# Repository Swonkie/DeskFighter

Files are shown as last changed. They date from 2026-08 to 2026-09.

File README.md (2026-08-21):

# DeskFighter

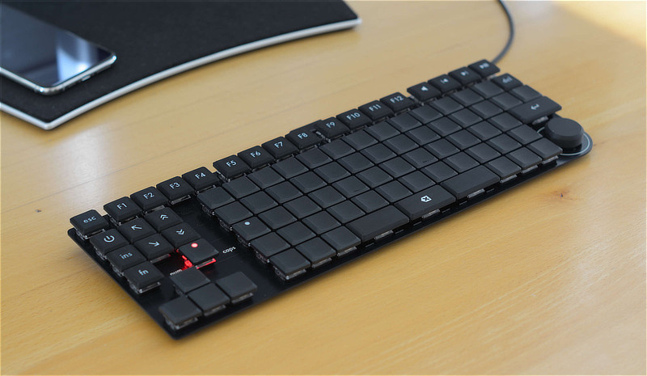
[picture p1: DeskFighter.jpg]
keyboard


These are the files used to design and build the DeskFighter keyboard.

There is an article which describes the process:

https://haldimann.app/DeskFighter/

## Organization

### 3D Printed Parts

Files in step and 3mf format to 3D print keycaps and other small parts required for the keyboard build.

### FreeCAD

FreeCAD files used to export the 3D printed parts above. If you want to make modifications, this is the most convenient option.

https://www.freecad.org/

### Keycaps Labels

Affinity and svg files used to design the labels. These were imported into FreeCAD.

### Matrix Layout

Spreadsheet used to plan the keyboard matrix layout.

### PCB

KiCad project files used to design the printed circuit board (PCB). The actual manufacturing files (gerber and drill files) are not included, but can be exported from KiCad. Those are then sent to a PCB manufacturer which will make the board.

Also includes the MacroPad files — a test project to figure out some things with a small PCB before ordering the large DeskFighter PCB.

https://www.kicad.org/

## Additional parts required

The mentioned shops are just suggestions. All parts are available in other shops too.

| Shop | Item | Quantity |
| --- | --- | ---: |
| [Keebart](https://www.keebart.com/) | Switches (Kailh Choc V2 with 2 pins) | 100 |
| | THT keycaps blank | 60 |
| | THT keycaps with dot | 2 |
| | THT keycaps with tactile marker | 2 |
| [Max Gaming](https://www.maxgaming.com/shop) | Durock V3 plate-mounted stabilizer set | 1 |
| [DigiKey](https://www.digikey.com/) | [Various electronics components](https://www.digikey.com/en/mylists/list/9PG9QW3RYC) | – |
| [CNC Kitchen](https://cnckitchen.store/) | M2 heat-set inserts | 20 |
| | Installation tip set (optional) | 1 |
| [AliExpress](https://www.aliexpress.com/) | M2 × 5 mm screws, black, Torx | 10 |
| | Rubber feet, 8 mm × 3 mm, self-adhesive | 20 |

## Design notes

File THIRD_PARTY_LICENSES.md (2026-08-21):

Some files in this repository are licensed differently than the repository itself:

## SW_Kailh_Choc_V2.step

3D model by GitHub user koktoh licensed under CC BY-NC-SA 4.0

https://github.com/koktoh/keyswitch_model/blob/master/choc/v2/step/red.step

https://creativecommons.org/licenses/by-nc-sa/4.0/

### Changes made

- removed third pin, which is not present in newer version of the switch

## Stabilizer_2.00u.step

3D model by GitHub user koktoh licensed under CC BY-NC-SA 4.0

https://github.com/koktoh/keyswitch_model/blob/master/stabilizer/plate_mount/step/stabilizer_2u.step

https://creativecommons.org/licenses/by-nc-sa/4.0/

## RING23-920205-TH.step

3D model by manufacturer (Same Sky)

https://www.sameskydevices.com/product/resource/digikey3dmodel/ring23-920205-th

https://www.sameskydevices.com/cad-model-terms

## GSB1C41110SSHR.step

3D model by manufacturer (Amphenol ICC)

Provided by DigiKey with download agreement on same page:

https://www.digikey.com/en/models/21623839

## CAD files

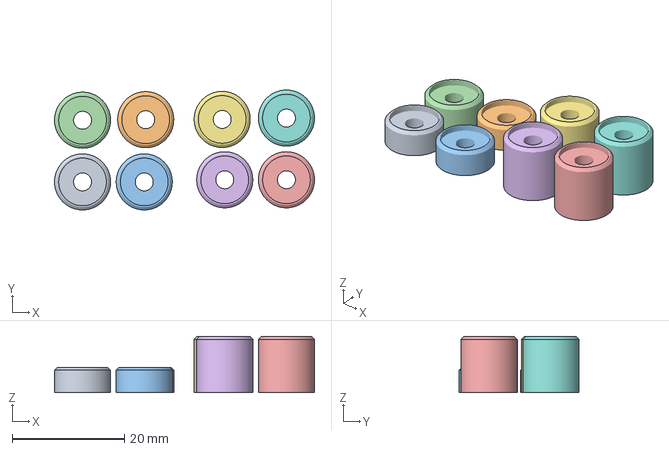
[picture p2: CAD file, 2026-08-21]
3D Printed Parts/Feet.3mf
46.3 x 21.4 x 10.0 mm
Foot Front.step x 4
Standoff x 4

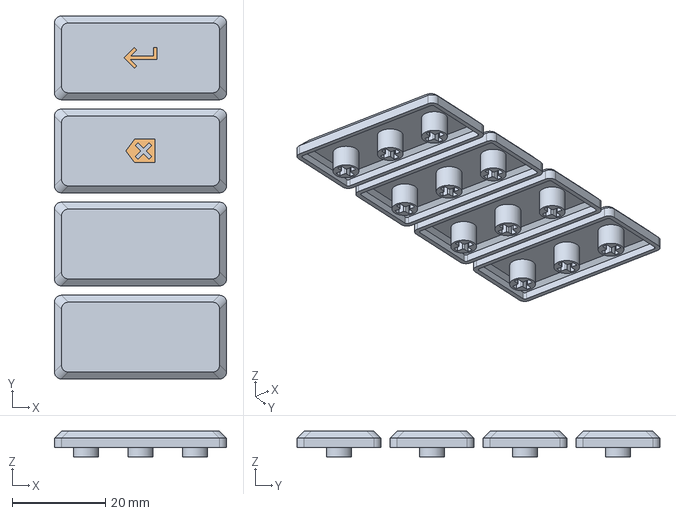
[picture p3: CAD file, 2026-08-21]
FreeCAD/Keycaps 2u.FCStd
37.0 x 78.0 x 5.50 mm
Keycaps
Labels

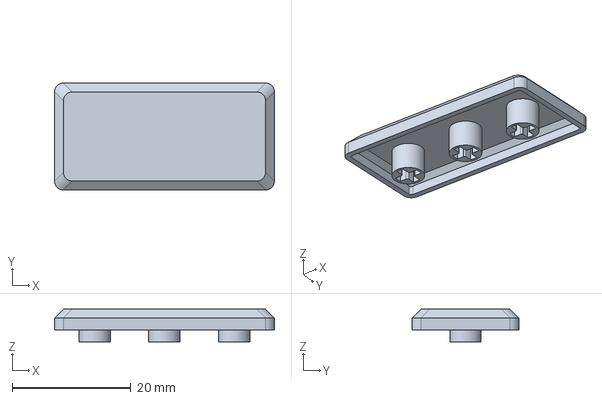
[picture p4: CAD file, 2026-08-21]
PCB/DeskFighter/3dmodels/Keycap_2u_blank.step
37.0 x 18.0 x 5.50 mm

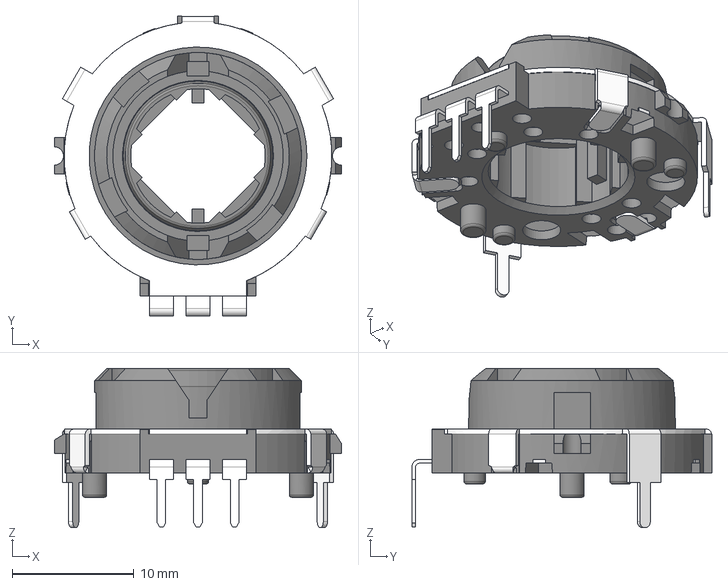
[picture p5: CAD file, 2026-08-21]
PCB/MacroPad/3dmodels/RING23-920205-TH.step
23.6 x 24.6 x 13.1 mm

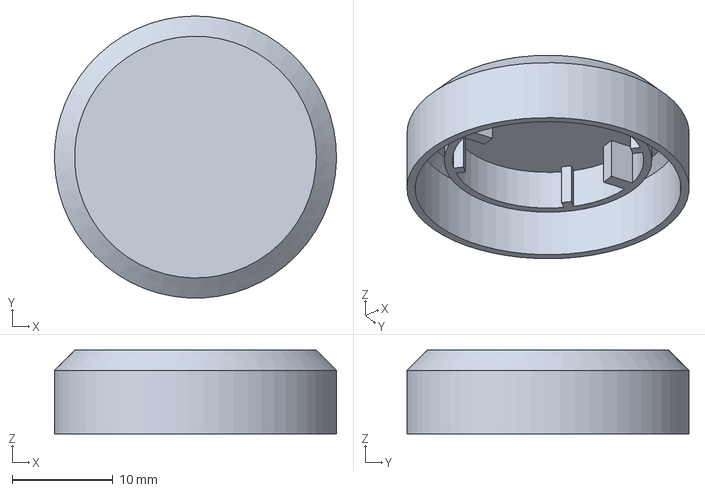
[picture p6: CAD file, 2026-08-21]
3D Printed Parts/Encoder Cap.step
28.0 x 28.0 x 8.30 mm

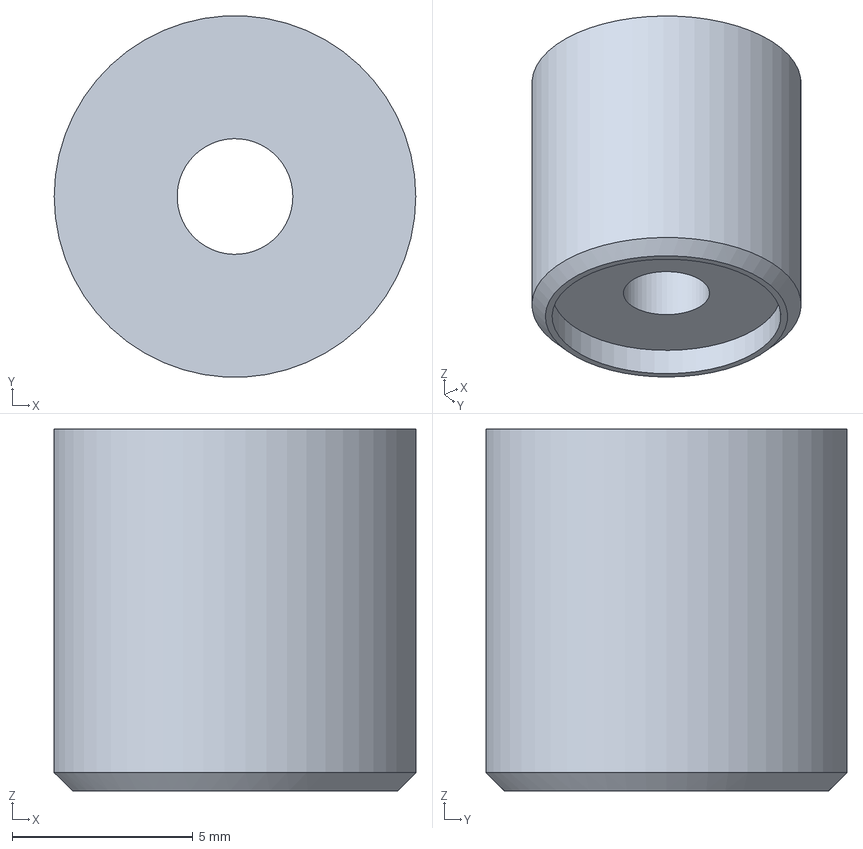
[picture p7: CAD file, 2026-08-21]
FreeCAD/Foot Back.FCStd
10.0 x 9.98 x 10.0 mm

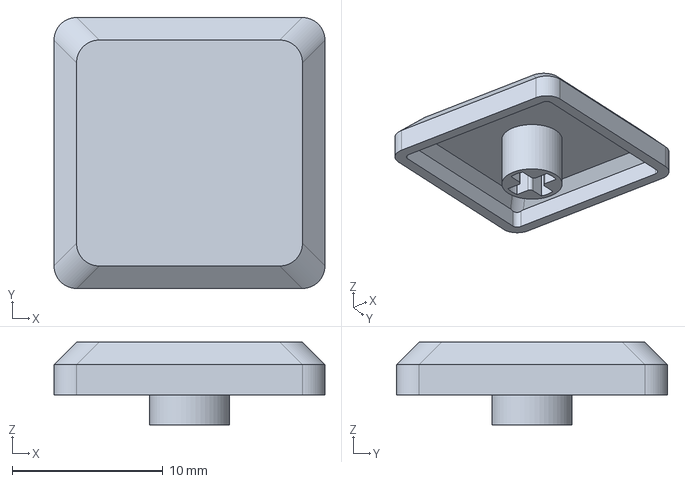
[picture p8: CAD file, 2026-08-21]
PCB/DeskFighter/3dmodels/Keycap_1u_blank.step
18.0 x 18.0 x 5.50 mm

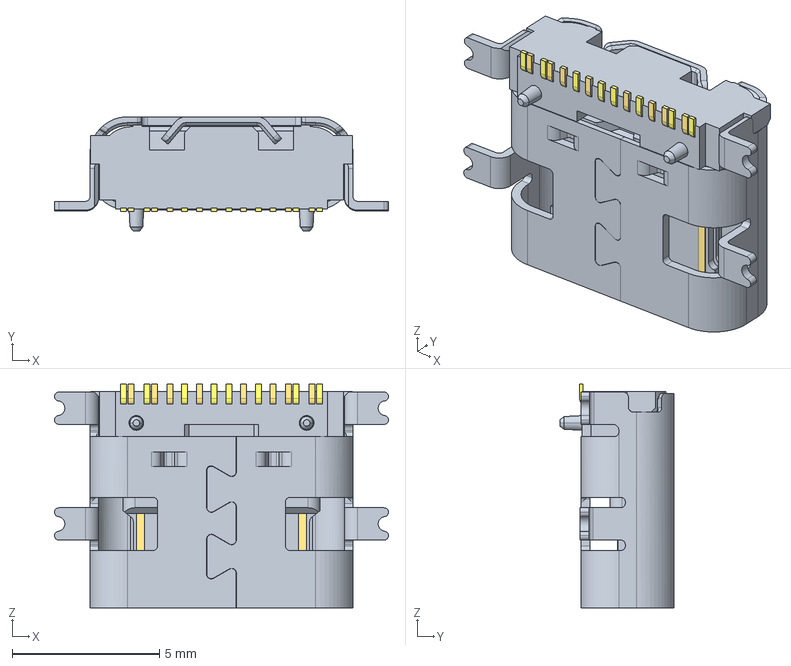
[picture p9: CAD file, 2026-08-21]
PCB/MacroPad/3dmodels/GSB1C41110SSHR.step
11.3 x 3.89 x 7.60 mm

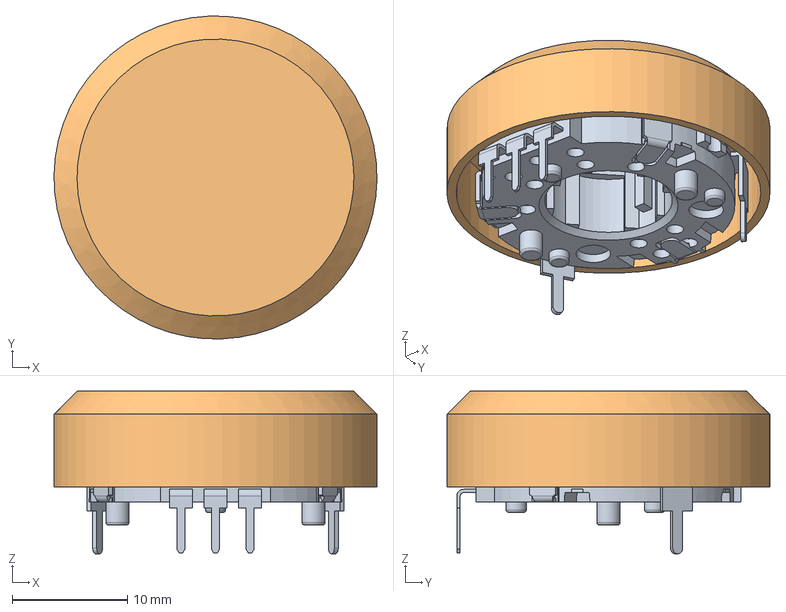
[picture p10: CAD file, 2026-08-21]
FreeCAD/Encoder Cap.FCStd
28.0 x 28.0 x 14.1 mm
Encoder
Encoder Cap

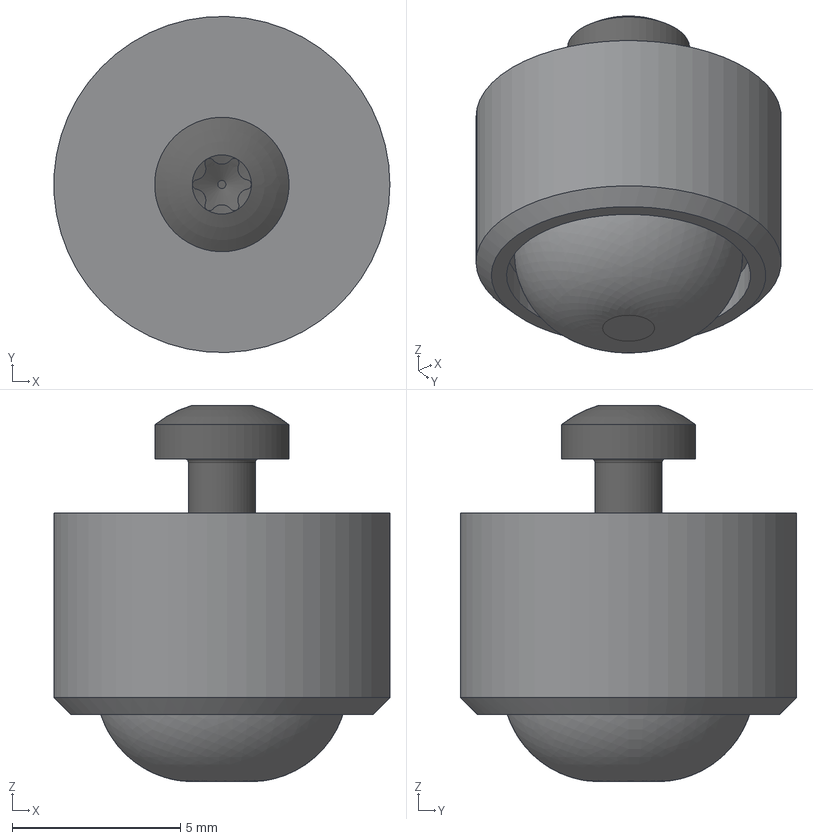
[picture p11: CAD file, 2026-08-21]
PCB/MacroPad/3dmodels/MacroPad_Foot.step
9.99 x 10.00 x 11.2 mm
Standoff
M2x4-Screw

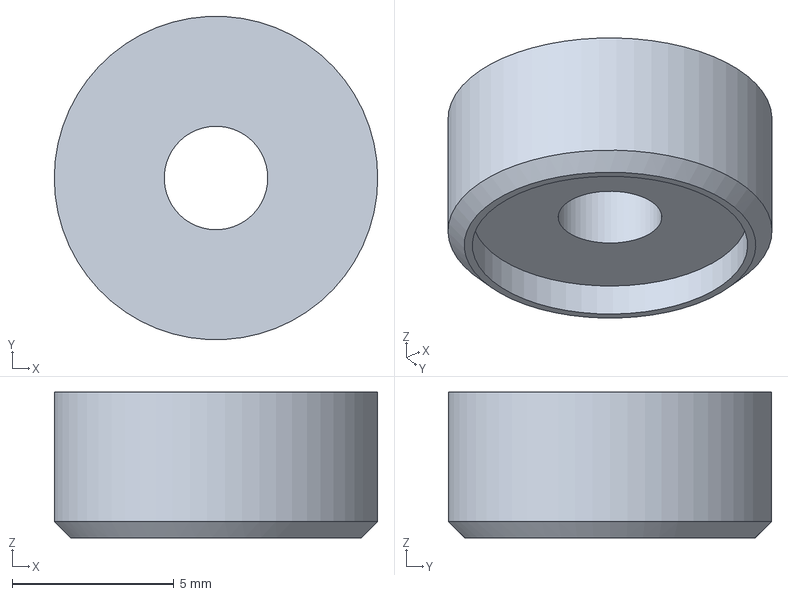
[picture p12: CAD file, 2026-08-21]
FreeCAD/Foot Front.FCStd
10.0 x 9.99 x 4.50 mm

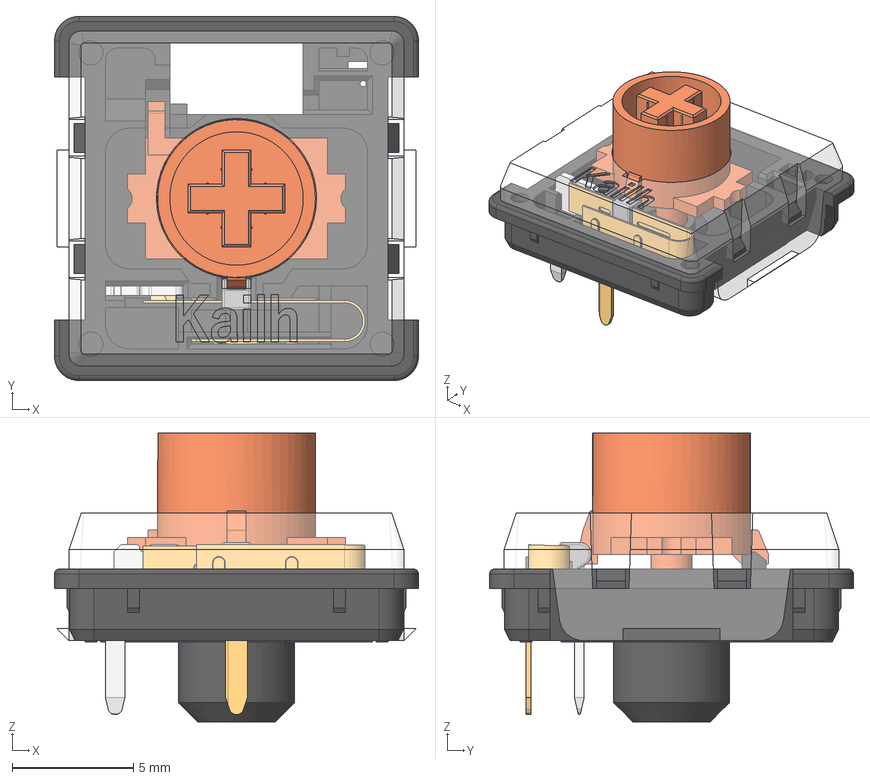
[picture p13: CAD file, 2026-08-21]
PCB/DeskFighter/3dmodels/SW_Kailh_Choc_V2.step
15.0 x 15.0 x 11.9 mm
bottom
contact
pin1
stem
top
pin2

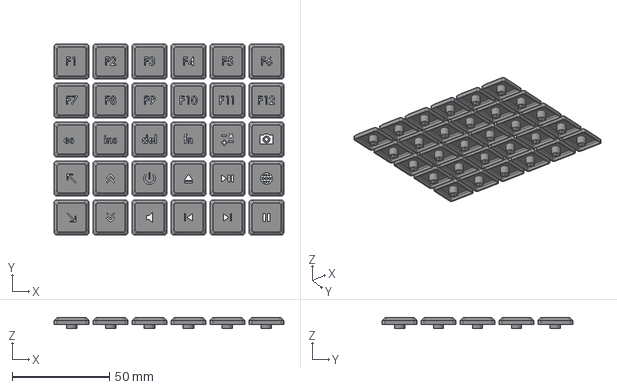
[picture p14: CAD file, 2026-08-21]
3D Printed Parts/Keycaps 1u.step
118.0 x 98.0 x 5.50 mm
Keycaps
Labels

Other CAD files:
3D Printed Parts/Foot Back.step
3D Printed Parts/Keycaps 2u.step
FreeCAD/Keycaps 1u.FCStd
3D Printed Parts/Encoder Cap.3mf
3D Printed Parts/Foot Front.step
3D Printed Parts/Keycaps.3mf
FreeCAD/KiCad Foot.FCStd
PCB/DeskFighter/3dmodels/Encoder_Cap.step
PCB/DeskFighter/3dmodels/Stabilizer_2.00u.step
PCB/MacroPad/3dmodels/Encoder_Cap.step
PCB/MacroPad/3dmodels/Stabilizer_2.00u.step

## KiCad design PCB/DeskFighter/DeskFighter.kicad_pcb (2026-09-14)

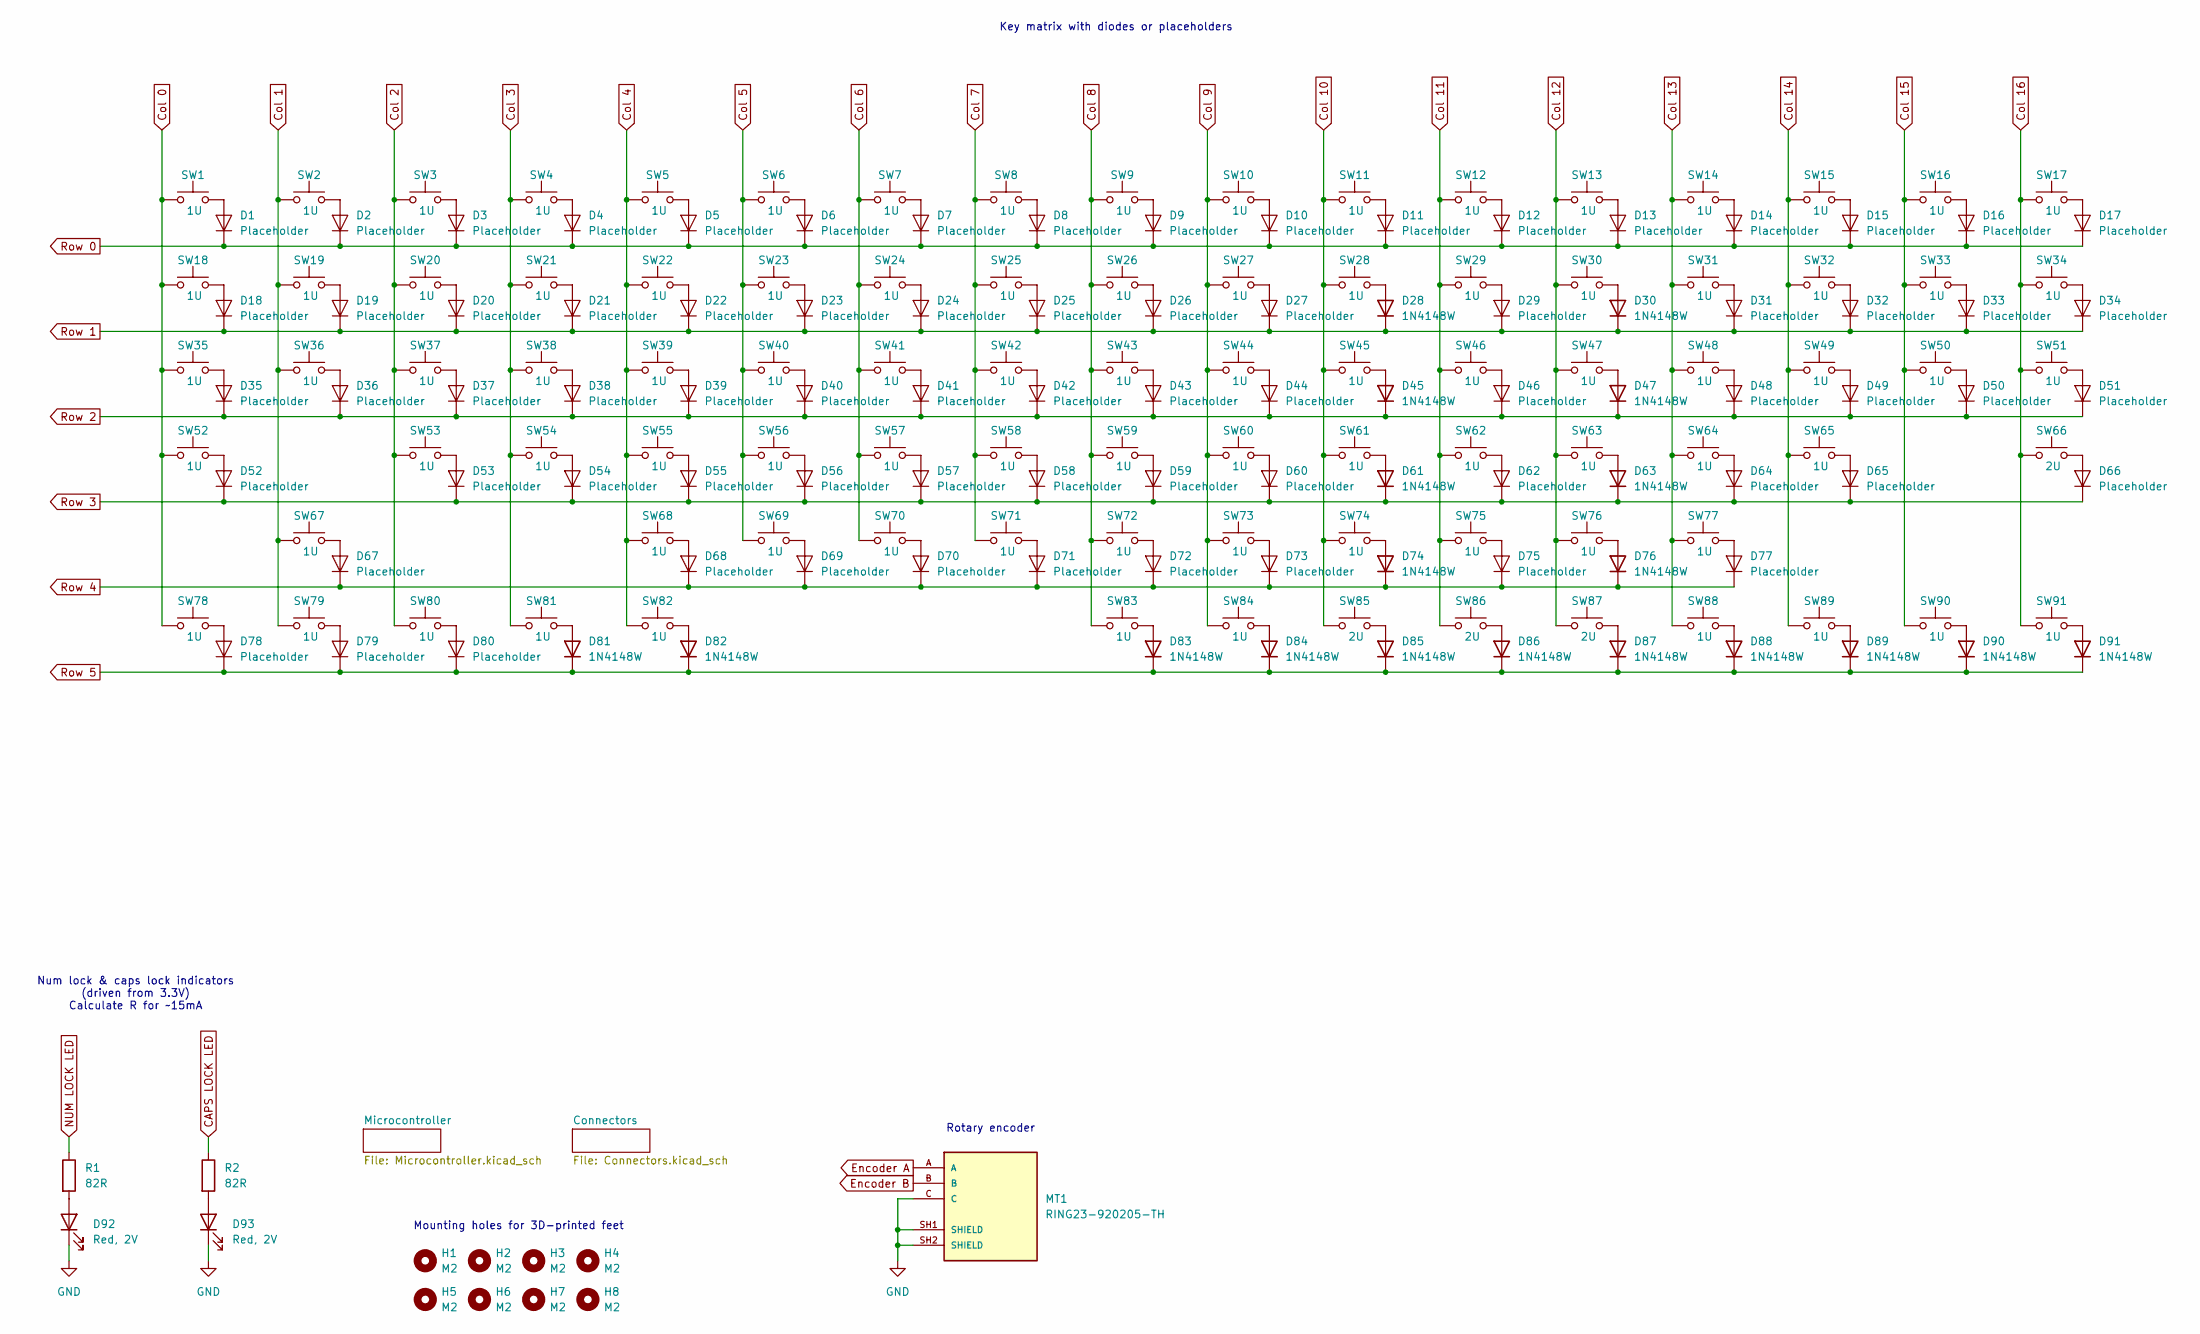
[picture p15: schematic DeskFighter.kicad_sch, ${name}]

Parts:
D1, D2, D3, D4, D5, D6, D7, D8, D9, D10, D11, D12, D13, D14, D15, D16, D17, D18, D19, D20, D21, D22, D23, D24, D25, D26, D27, D29, D31, D32, D33, D34, D35, D36, D37, D38, D39, D40, D41, D42, D43, D44, D46, D48, D49, D50, D51, D52, D53, D54, D55, D56, D57, D58, D59, D60, D62, D64, D65, D66, D67, D68, D69, D70, D71, D72, D73, D75, D77, D78, D79, D80: Placeholder; DiodePlaceholder
D28, D30, D45, D47, D61, D63, D74, D76, D81, D82, D83, D84, D85, D86, D87, D88, D89, D90, D91: 1N4148W; D_SOD-123_Handsolder
D92, D93: Red, 2V; LED_0805_2012Metric_Pad1.15x1.40mm_HandSolder
H1, H2, H3, H4, H5, H6, H7, H8: M2; MountingHole_2.2mm_M2_ISO14580_Pad_10mm_Standoffs
MT1: RING23-920205-TH; PARTREV 1.0
R1, R2: 82R; R_0805_2012Metric_Pad1.20x1.40mm_HandSolder
SW1, SW2, SW3, SW4, SW5, SW6, SW7, SW8, SW9, SW10, SW11, SW12, SW13, SW14, SW15, SW16, SW17, SW18, SW19, SW20, SW21, SW22, SW23, SW24, SW25, SW26, SW27, SW28, SW29, SW30, SW31, SW32, SW33, SW34, SW35, SW36, SW37, SW38, SW39, SW40, SW41, SW42, SW43, SW44, SW45, SW46, SW47, SW48, SW49, SW50, SW51, SW52, SW53, SW54, SW55, SW56, SW57, SW58, SW59, SW60, SW61, SW62, SW63, SW64, SW65, SW67, SW68, SW69, SW70, SW71, SW72, SW73, SW74, SW75, SW76, SW77, SW78, SW79, SW80, SW81, SW82, SW83, SW84, SW88, SW89, SW90, SW91: 1U; SW_Kailh_Choc_V2_1.00u
SW66, SW85, SW86, SW87: 2U; SW_Kailh_Choc_V2_2.00u

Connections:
CAPS LOCK LED: R2.1; also elsewhere on the board
Col 0: SW1.1, SW18.1, SW35.1, SW52.1, SW78.1; also elsewhere on the board
Col 1: SW2.1, SW19.1, SW36.1, SW67.1, SW79.1; also elsewhere on the board
Col 2: SW3.1, SW20.1, SW37.1, SW53.1, SW80.1; also elsewhere on the board
Col 3: SW4.1, SW21.1, SW38.1, SW54.1, SW81.1; also elsewhere on the board
Col 4: SW5.1, SW22.1, SW39.1, SW55.1, SW68.1, SW82.1; also elsewhere on the board
Col 5: SW6.1, SW23.1, SW40.1, SW56.1, SW69.1; also elsewhere on the board
Col 6: SW7.1, SW24.1, SW41.1, SW57.1, SW70.1; also elsewhere on the board
Col 7: SW8.1, SW25.1, SW42.1, SW58.1, SW71.1; also elsewhere on the board
Col 8: SW9.1, SW26.1, SW43.1, SW59.1, SW72.1, SW83.1; also elsewhere on the board
Col 9: SW10.1, SW27.1, SW44.1, SW60.1, SW73.1, SW84.1; also elsewhere on the board
Col 10: SW11.1, SW28.1, SW45.1, SW61.1, SW74.1, SW85.1; also elsewhere on the board
Col 11: SW12.1, SW29.1, SW46.1, SW62.1, SW75.1, SW86.1; also elsewhere on the board
Col 12: SW13.1, SW30.1, SW47.1, SW63.1, SW76.1, SW87.1; also elsewhere on the board
Col 13: SW14.1, SW31.1, SW48.1, SW64.1, SW77.1, SW88.1; also elsewhere on the board
Col 14: SW15.1, SW32.1, SW49.1, SW65.1, SW89.1; also elsewhere on the board
Col 15: SW16.1, SW33.1, SW50.1, SW90.1; also elsewhere on the board
Col 16: SW17.1, SW34.1, SW51.1, SW66.1, SW91.1; also elsewhere on the board
Encoder A: MT1.A; also elsewhere on the board
Encoder B: MT1.B; also elsewhere on the board
GND: D92.1 (K), D93.1 (K), MT1.C, MT1.SH1 (SHIELD), MT1.SH2 (SHIELD); also elsewhere on the board
NUM LOCK LED: R1.1; also elsewhere on the board
unnamed: D1.2 (A), SW1.2
unnamed: D2.2 (A), SW2.2
unnamed: D3.2 (A), SW3.2
unnamed: D4.2 (A), SW4.2
unnamed: D5.2 (A), SW5.2
unnamed: D6.2 (A), SW6.2
unnamed: D7.2 (A), SW7.2
unnamed: D8.2 (A), SW8.2
unnamed: D9.2 (A), SW9.2
unnamed: D10.2 (A), SW10.2
unnamed: D11.2 (A), SW11.2
unnamed: D12.2 (A), SW12.2
unnamed: D13.2 (A), SW13.2
unnamed: D14.2 (A), SW14.2
unnamed: D15.2 (A), SW15.2
unnamed: D16.2 (A), SW16.2
unnamed: D17.2 (A), SW17.2
unnamed: D18.2 (A), SW18.2
unnamed: D19.2 (A), SW19.2
unnamed: D20.2 (A), SW20.2
unnamed: D21.2 (A), SW21.2
unnamed: D22.2 (A), SW22.2
unnamed: D23.2 (A), SW23.2
unnamed: D24.2 (A), SW24.2
unnamed: D25.2 (A), SW25.2
unnamed: D26.2 (A), SW26.2
unnamed: D27.2 (A), SW27.2
unnamed: D28.2 (A), SW28.2
unnamed: D29.2 (A), SW29.2
unnamed: D30.2 (A), SW30.2
unnamed: D31.2 (A), SW31.2
unnamed: D32.2 (A), SW32.2
unnamed: D33.2 (A), SW33.2
unnamed: D34.2 (A), SW34.2
unnamed: D35.2 (A), SW35.2
unnamed: D36.2 (A), SW36.2
unnamed: D37.2 (A), SW37.2
unnamed: D38.2 (A), SW38.2
unnamed: D39.2 (A), SW39.2
unnamed: D40.2 (A), SW40.2
unnamed: D41.2 (A), SW41.2
unnamed: D42.2 (A), SW42.2
unnamed: D43.2 (A), SW43.2
unnamed: D44.2 (A), SW44.2
unnamed: D45.2 (A), SW45.2
unnamed: D46.2 (A), SW46.2
unnamed: D47.2 (A), SW47.2
unnamed: D48.2 (A), SW48.2
unnamed: D49.2 (A), SW49.2
unnamed: D50.2 (A), SW50.2
unnamed: D51.2 (A), SW51.2
unnamed: D52.2 (A), SW52.2
unnamed: D53.2 (A), SW53.2
unnamed: D54.2 (A), SW54.2
unnamed: D55.2 (A), SW55.2
unnamed: D56.2 (A), SW56.2
unnamed: D57.2 (A), SW57.2
unnamed: D58.2 (A), SW58.2
unnamed: D59.2 (A), SW59.2
unnamed: D60.2 (A), SW60.2
unnamed: D61.2 (A), SW61.2
unnamed: D62.2 (A), SW62.2
unnamed: D63.2 (A), SW63.2
unnamed: D64.2 (A), SW64.2
unnamed: D65.2 (A), SW65.2
unnamed: D66.2 (A), SW66.2
unnamed: D67.2 (A), SW67.2
unnamed: D68.2 (A), SW68.2
unnamed: D69.2 (A), SW69.2
unnamed: D70.2 (A), SW70.2
unnamed: D71.2 (A), SW71.2
unnamed: D72.2 (A), SW72.2
unnamed: D73.2 (A), SW73.2
unnamed: D74.2 (A), SW74.2
unnamed: D75.2 (A), SW75.2
unnamed: D76.2 (A), SW76.2
unnamed: D77.2 (A), SW77.2
unnamed: D78.2 (A), SW78.2
unnamed: D79.2 (A), SW79.2
unnamed: D80.2 (A), SW80.2
unnamed: D81.2 (A), SW81.2
unnamed: D82.2 (A), SW82.2
unnamed: D83.2 (A), SW83.2
unnamed: D84.2 (A), SW84.2
unnamed: D85.2 (A), SW85.2
unnamed: D86.2 (A), SW86.2
unnamed: D87.2 (A), SW87.2
unnamed: D88.2 (A), SW88.2
unnamed: D89.2 (A), SW89.2
unnamed: D90.2 (A), SW90.2
unnamed: D91.2 (A), SW91.2
unnamed: D92.2 (A), R1.2
unnamed: D93.2 (A), R2.2
Row 0: D1.1 (K), D2.1 (K), D3.1 (K), D4.1 (K), D5.1 (K), D6.1 (K), D7.1 (K), D8.1 (K), D9.1 (K), D10.1 (K), D11.1 (K), D12.1 (K), D13.1 (K), D14.1 (K), D15.1 (K), D16.1 (K), D17.1 (K); also elsewhere on the board
Row 1: D18.1 (K), D19.1 (K), D20.1 (K), D21.1 (K), D22.1 (K), D23.1 (K), D24.1 (K), D25.1 (K), D26.1 (K), D27.1 (K), D28.1 (K), D29.1 (K), D30.1 (K), D31.1 (K), D32.1 (K), D33.1 (K), D34.1 (K); also elsewhere on the board
Row 2: D35.1 (K), D36.1 (K), D37.1 (K), D38.1 (K), D39.1 (K), D40.1 (K), D41.1 (K), D42.1 (K), D43.1 (K), D44.1 (K), D45.1 (K), D46.1 (K), D47.1 (K), D48.1 (K), D49.1 (K), D50.1 (K), D51.1 (K); also elsewhere on the board
Row 3: D52.1 (K), D53.1 (K), D54.1 (K), D55.1 (K), D56.1 (K), D57.1 (K), D58.1 (K), D59.1 (K), D60.1 (K), D61.1 (K), D62.1 (K), D63.1 (K), D64.1 (K), D65.1 (K), D66.1 (K); also elsewhere on the board
Row 4: D67.1 (K), D68.1 (K), D69.1 (K), D70.1 (K), D71.1 (K), D72.1 (K), D73.1 (K), D74.1 (K), D75.1 (K), D76.1 (K), D77.1 (K); also elsewhere on the board
Row 5: D78.1 (K), D79.1 (K), D80.1 (K), D81.1 (K), D82.1 (K), D83.1 (K), D84.1 (K), D85.1 (K), D86.1 (K), D87.1 (K), D88.1 (K), D89.1 (K), D90.1 (K), D91.1 (K); also elsewhere on the board

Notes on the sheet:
Key matrix with diodes or placeholders
Rotary encoder
Mounting holes for 3D-printed feet
Num lock & caps lock indicators (driven from 3.3V) Calculate R for ~15mA

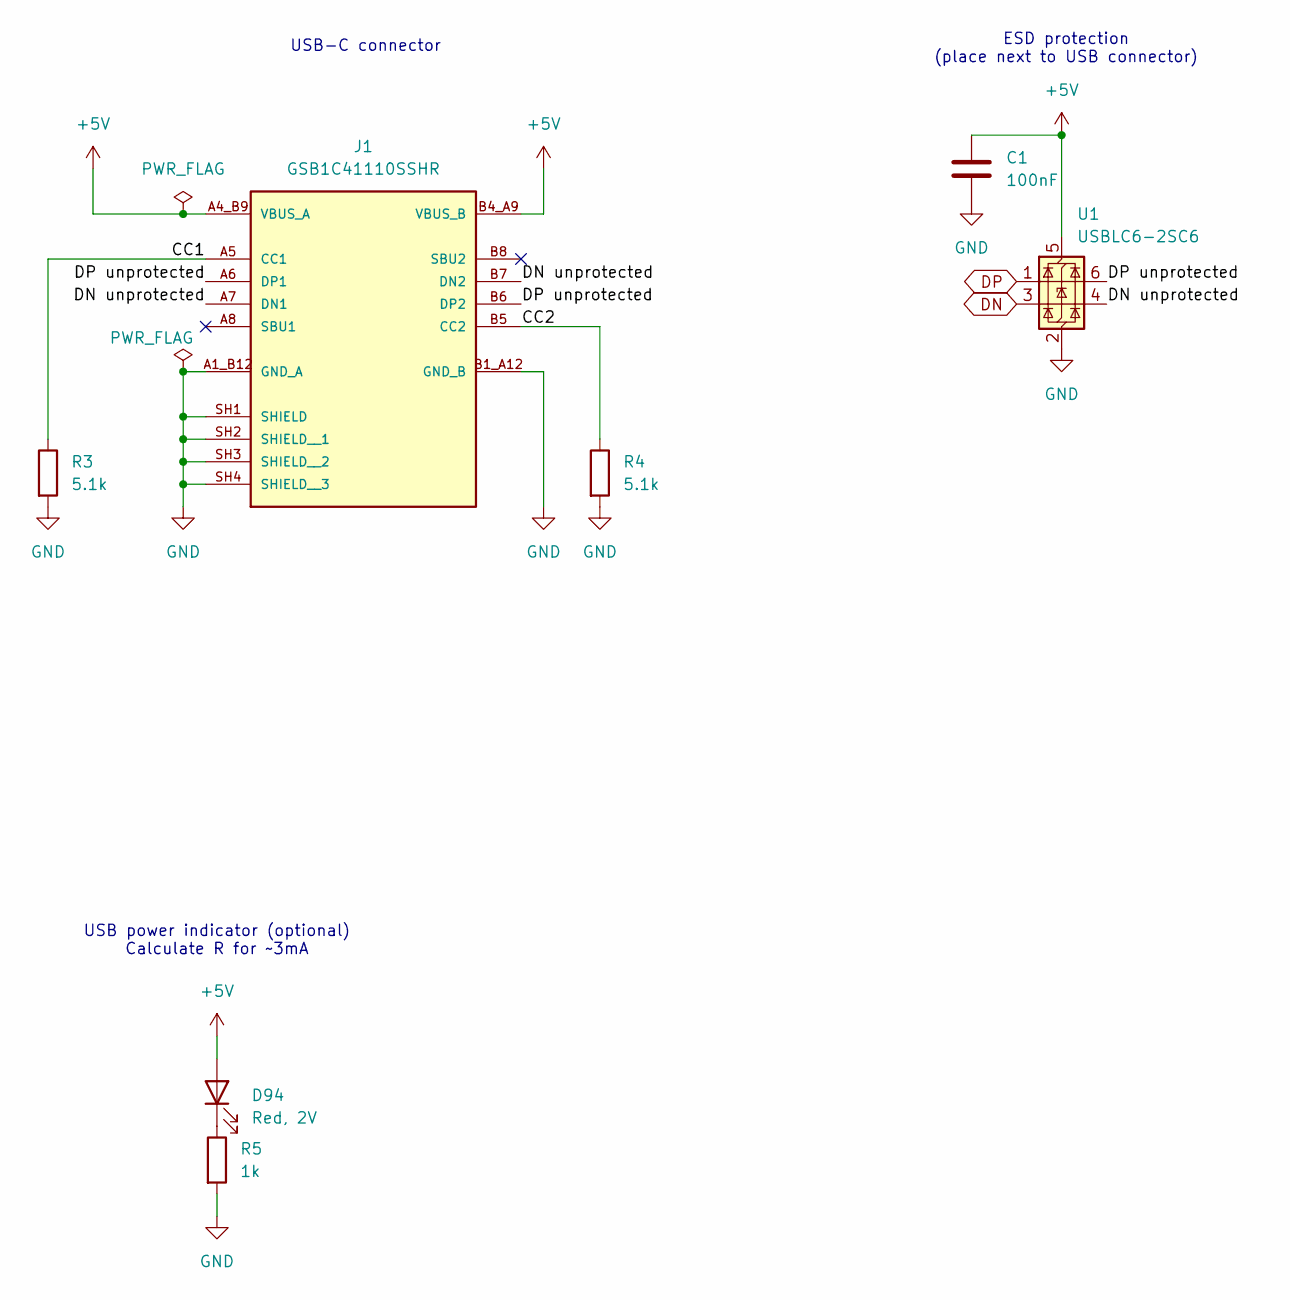
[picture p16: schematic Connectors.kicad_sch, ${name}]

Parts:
C1: 100nF; C_0805_2012Metric_Pad1.18x1.45mm_HandSolder
D94: Red, 2V; LED_0805_2012Metric_Pad1.15x1.40mm_HandSolder
J1: GSB1C41110SSHR; AMPHENOL_GSB1C41110SSHR; PARTREV AX1
R3, R4: 5.1k; R_0805_2012Metric_Pad1.20x1.40mm_HandSolder
R5: 1k; R_0805_2012Metric_Pad1.20x1.40mm_HandSolder
U1: USBLC6-2SC6; SOT-23-6_Handsoldering

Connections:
+5V: C1.1, D94.2 (A), J1.A4_B9 (VBUS_A), J1.B4_A9 (VBUS_B), U1.5 (VBUS); also elsewhere on the board
/Connectors/CC1: J1.A5 (CC1), R3.1
/Connectors/CC2: J1.B5 (CC2), R4.1
/Connectors/DN unprotected: J1.A7 (DN1), J1.B7 (DN2), U1.4 (I/O2)
/Connectors/DP unprotected: J1.A6 (DP1), J1.B6 (DP2), U1.6 (I/O1)
DN: U1.3 (I/O2); also elsewhere on the board
DP: U1.1 (I/O1); also elsewhere on the board
GND: C1.2, J1.A1_B12 (GND_A), J1.B1_A12 (GND_B), J1.SH1 (SHIELD), J1.SH2 (SHIELD__1), J1.SH3 (SHIELD__2), J1.SH4 (SHIELD__3), R3.2, R4.2, R5.2, U1.2 (GND); also elsewhere on the board
unnamed: D94.1 (K), R5.1

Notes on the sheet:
USB power indicator (optional) Calculate R for ~3mA
ESD protection (place next to USB connector)
USB-C connector

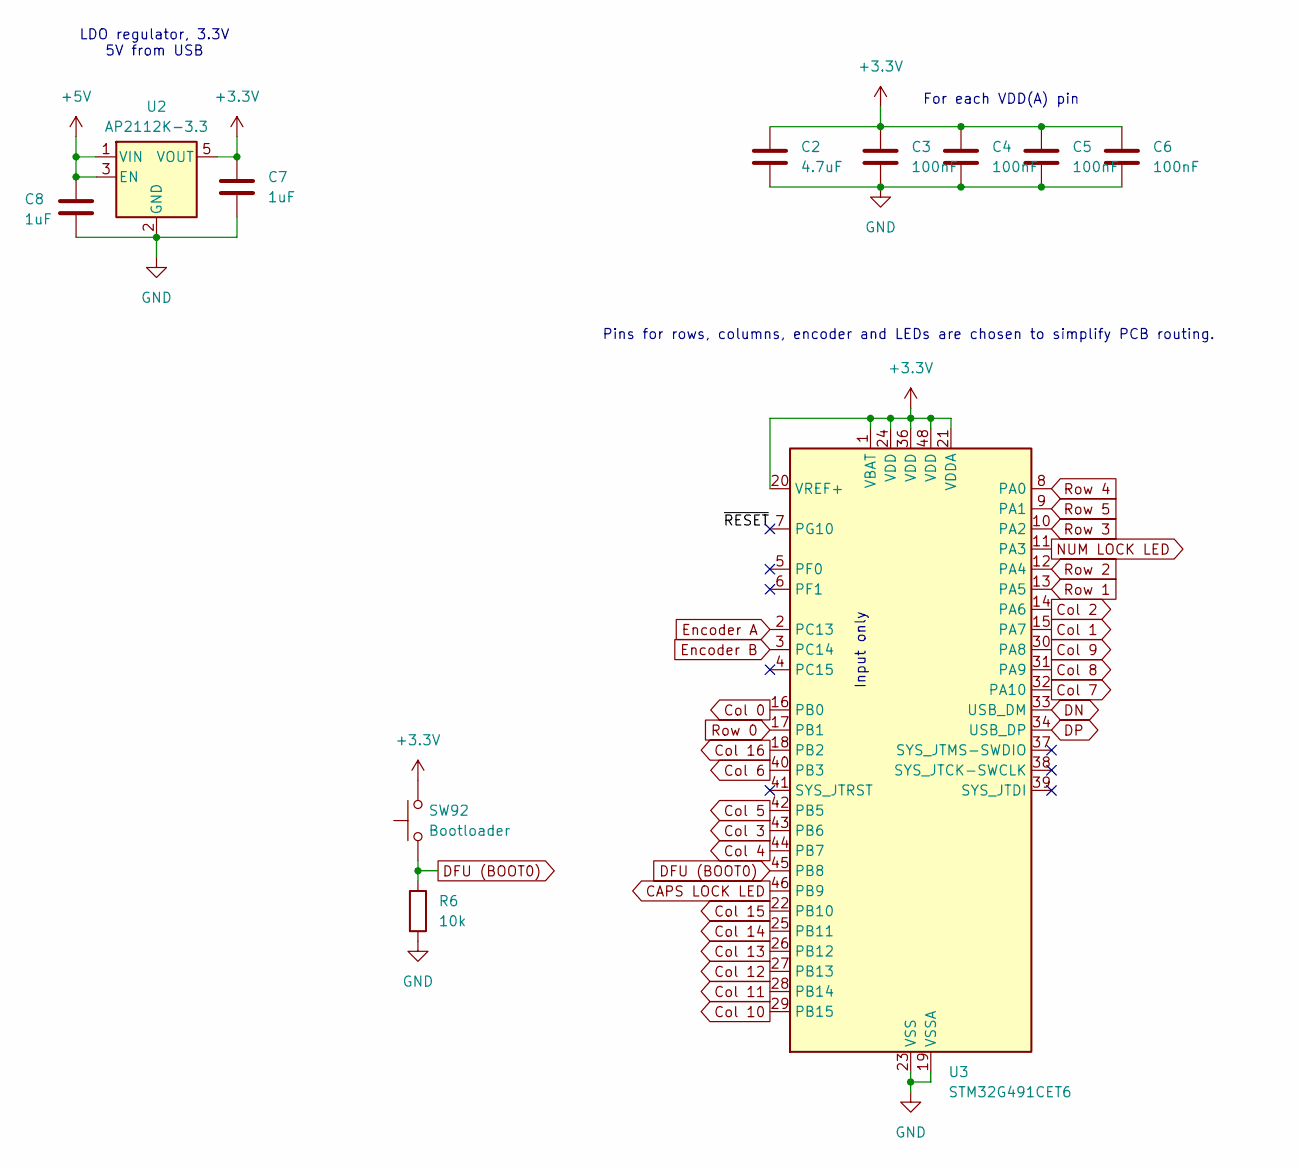
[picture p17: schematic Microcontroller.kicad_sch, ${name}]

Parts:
C2: 4.7uF; C_0805_2012Metric_Pad1.18x1.45mm_HandSolder
C3, C4, C5, C6: 100nF; C_0805_2012Metric_Pad1.18x1.45mm_HandSolder
C7, C8: 1uF; C_0805_2012Metric_Pad1.18x1.45mm_HandSolder
R6: 10k; R_0805_2012Metric_Pad1.20x1.40mm_HandSolder
SW92: Bootloader; SW_SPST_PTS645Sx43SMTR92
U2: AP2112K-3.3; SOT-23-5_HandSoldering
U3: STM32G491CET6; LQFP-48_7x7mm_P0.5mm

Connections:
+3.3V: C2.1, C3.1, C4.1, C5.1, C6.1, C7.1, SW92.2, U2.5 (VOUT), U3.1 (VBAT), U3.20 (VREF+), U3.21 (VDDA), U3.24 (VDD), U3.36 (VDD), U3.48 (VDD)
+5V: C8.1, U2.1 (VIN), U2.3 (EN); also elsewhere on the board
/Microcontroller/~RESET: U3.7 (PG10)
CAPS LOCK LED: U3.46 (PB9); also elsewhere on the board
Col 0: U3.16 (PB0); also elsewhere on the board
Col 1: U3.15 (PA7); also elsewhere on the board
Col 2: U3.14 (PA6); also elsewhere on the board
Col 3: U3.43 (PB6); also elsewhere on the board
Col 4: U3.44 (PB7); also elsewhere on the board
Col 5: U3.42 (PB5); also elsewhere on the board
Col 6: U3.40 (PB3); also elsewhere on the board
Col 7: U3.32 (PA10); also elsewhere on the board
Col 8: U3.31 (PA9); also elsewhere on the board
Col 9: U3.30 (PA8); also elsewhere on the board
Col 10: U3.29 (PB15); also elsewhere on the board
Col 11: U3.28 (PB14); also elsewhere on the board
Col 12: U3.27 (PB13); also elsewhere on the board
Col 13: U3.26 (PB12); also elsewhere on the board
Col 14: U3.25 (PB11); also elsewhere on the board
Col 15: U3.22 (PB10); also elsewhere on the board
Col 16: U3.18 (PB2); also elsewhere on the board
DFU (BOOT0): R6.1, SW92.1, U3.45 (PB8)
DN: U3.33 (USB_DM); also elsewhere on the board
DP: U3.34 (USB_DP); also elsewhere on the board
Encoder A: U3.2 (PC13); also elsewhere on the board
Encoder B: U3.3 (PC14); also elsewhere on the board
GND: C2.2, C3.2, C4.2, C5.2, C6.2, C7.2, C8.2, R6.2, U2.2 (GND), U3.19 (VSSA), U3.23 (VSS), U3.35 (VSS), U3.47 (VSS); also elsewhere on the board
NUM LOCK LED: U3.11 (PA3); also elsewhere on the board
Row 0: U3.17 (PB1); also elsewhere on the board
Row 1: U3.13 (PA5); also elsewhere on the board
Row 2: U3.12 (PA4); also elsewhere on the board
Row 3: U3.10 (PA2); also elsewhere on the board
Row 4: U3.8 (PA0); also elsewhere on the board
Row 5: U3.9 (PA1); also elsewhere on the board

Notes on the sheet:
Pins for rows, columns, encoder and LEDs are chosen to simplify PCB routing.
Input only
LDO regulator, 3.3V 5V from USB
For each VDD(A) pin

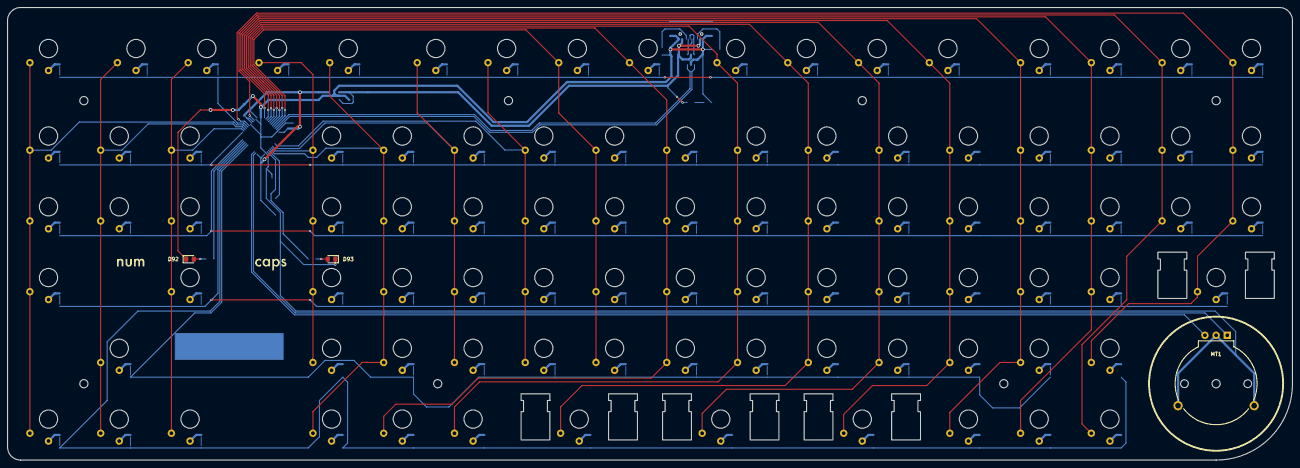
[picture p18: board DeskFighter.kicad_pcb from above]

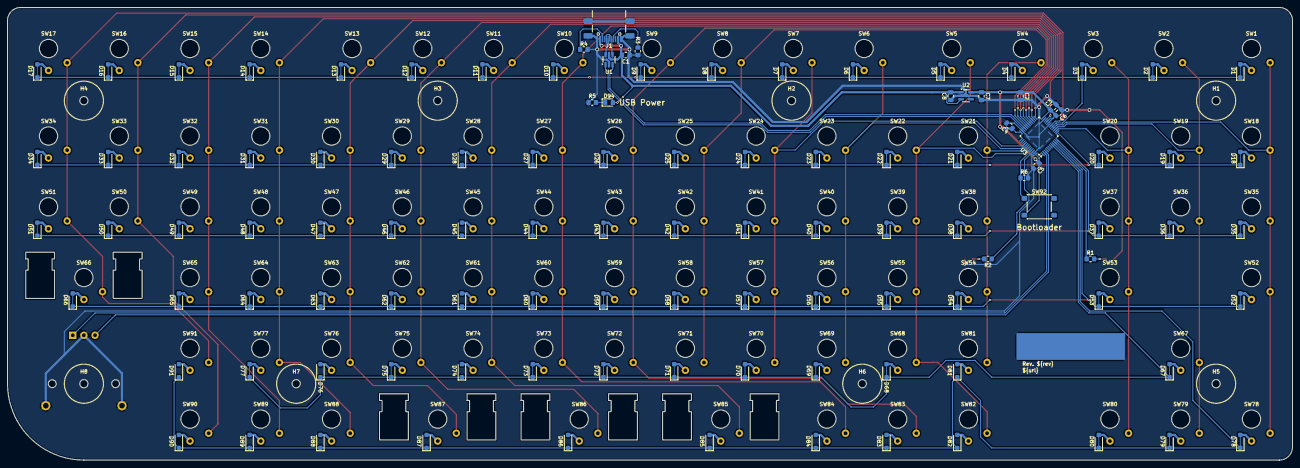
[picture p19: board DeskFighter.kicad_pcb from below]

Board: 2 copper layers, 345.0 x 121.5 mm, 213 parts (111 on the bottom side), 131 nets.

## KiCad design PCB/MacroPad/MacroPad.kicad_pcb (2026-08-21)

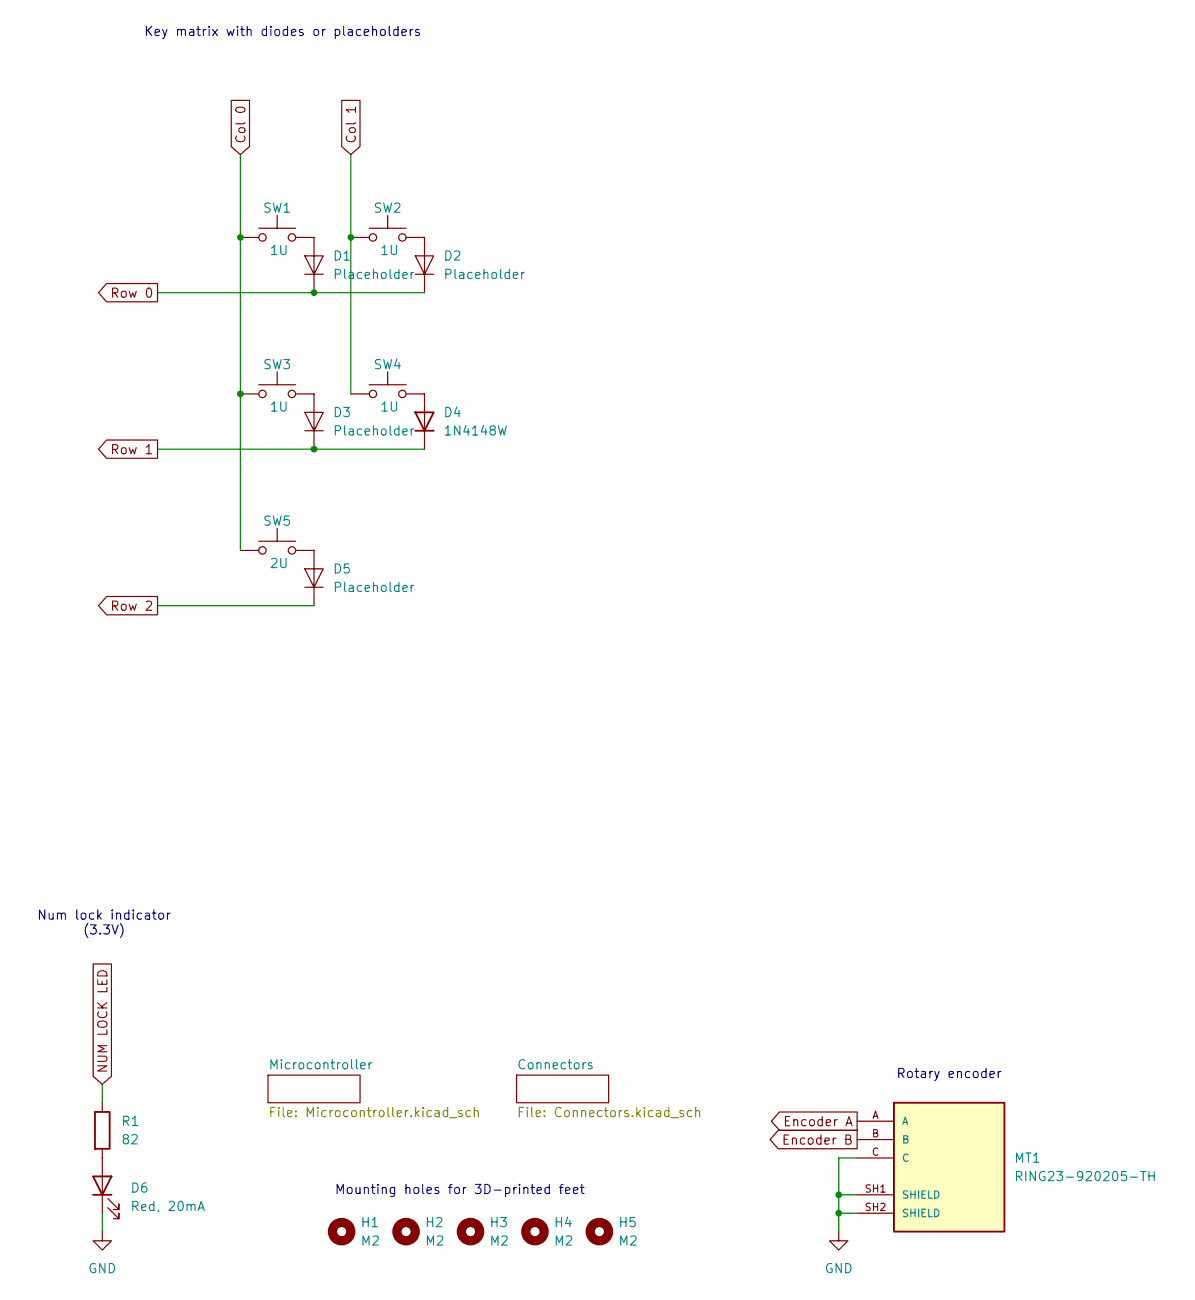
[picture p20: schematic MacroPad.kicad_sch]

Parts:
D1, D2, D3, D5: Placeholder; DiodePlaceholder
D4: 1N4148W; D_SOD-123_Handsolder; LCSC Part # C2099
D6: Red, 20mA; LED_0805_2012Metric_Pad1.15x1.40mm_HandSolder; LCSC Part # C2295
H1, H2, H3, H4, H5: M2; MountingHole_2.2mm_M2_ISO14580_Pad_10mm_Standoffs
MT1: RING23-920205-TH; PARTREV 1.0
R1: 82; R_0805_2012Metric_Pad1.20x1.40mm_HandSolder
SW1, SW2, SW3, SW4: 1U; SW_Kailh_Choc_V2_1.00u
SW5: 2U; SW_Kailh_Choc_V2_2.00u

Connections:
Col 0: SW1.1, SW3.1, SW5.1; also elsewhere on the board
Col 1: SW2.1, SW4.1; also elsewhere on the board
Encoder A: MT1.A; also elsewhere on the board
Encoder B: MT1.B; also elsewhere on the board
GND: D6.1 (K), MT1.C, MT1.SH1 (SHIELD), MT1.SH2 (SHIELD); also elsewhere on the board
NUM LOCK LED: R1.1; also elsewhere on the board
unnamed: D1.2 (A), SW1.2
unnamed: D2.2 (A), SW2.2
unnamed: D3.2 (A), SW3.2
unnamed: D4.2 (A), SW4.2
unnamed: D5.2 (A), SW5.2
unnamed: D6.2 (A), R1.2
Row 0: D1.1 (K), D2.1 (K); also elsewhere on the board
Row 1: D3.1 (K), D4.1 (K); also elsewhere on the board
Row 2: D5.1 (K); also elsewhere on the board

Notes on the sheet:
Key matrix with diodes or placeholders
Rotary encoder
Mounting holes for 3D-printed feet
Num lock indicator (3.3V)

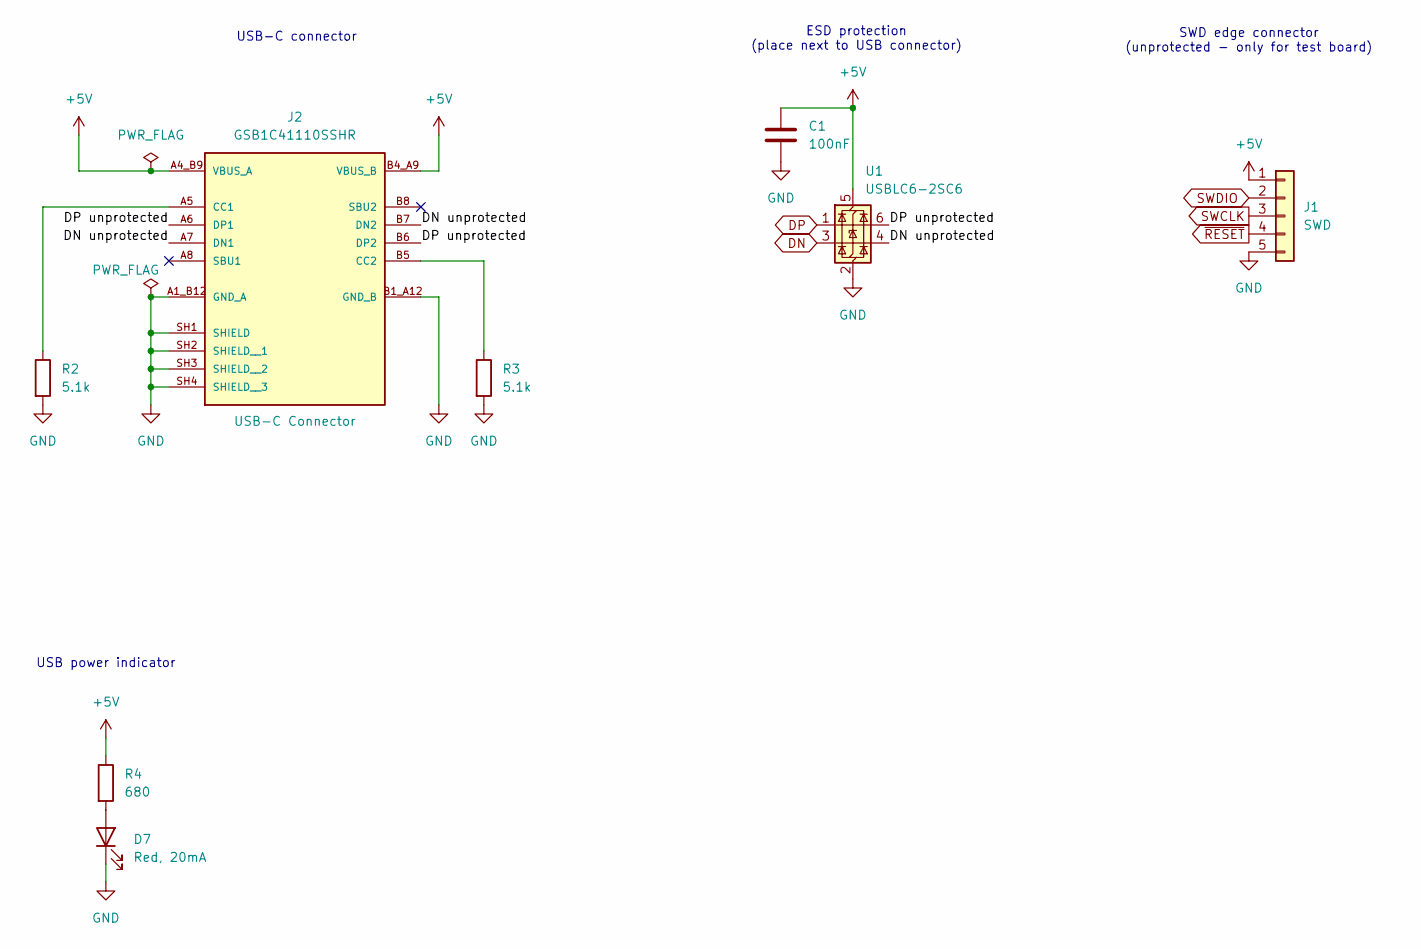
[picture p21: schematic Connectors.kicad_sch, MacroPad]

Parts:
C1: 100nF; C_0805_2012Metric_Pad1.18x1.45mm_HandSolder; LCSC Part # C1711
D7: Red, 20mA; LED_0805_2012Metric_Pad1.15x1.40mm_HandSolder; LCSC Part # C2295
J1: SWD; SWD_Programming_Edge_Connector_Single
J2: GSB1C41110SSHR; AMPHENOL_GSB1C41110SSHR; PARTREV AX1; LCSC Part # C34260841
R2, R3: 5.1k; R_0805_2012Metric_Pad1.20x1.40mm_HandSolder
R4: 680; R_0805_2012Metric_Pad1.20x1.40mm_HandSolder
U1: USBLC6-2SC6; SOT-23-6_Handsoldering; LCSC Part # C7519

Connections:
+5V: C1.1, J1.1, J2.A4_B9 (VBUS_A), J2.B4_A9 (VBUS_B), R4.1, U1.5 (VBUS); also elsewhere on the board
/Connectors/DN unprotected: J2.A7 (DN1), J2.B7 (DN2), U1.4 (I/O2)
/Connectors/DP unprotected: J2.A6 (DP1), J2.B6 (DP2), U1.6 (I/O1)
DN: U1.3 (I/O2); also elsewhere on the board
DP: U1.1 (I/O1); also elsewhere on the board
GND: C1.2, D7.1 (K), J1.5, J2.A1_B12 (GND_A), J2.B1_A12 (GND_B), J2.SH1 (SHIELD), J2.SH2 (SHIELD__1), J2.SH3 (SHIELD__2), J2.SH4 (SHIELD__3), R2.2, R3.2, U1.2 (GND); also elsewhere on the board
unnamed: D7.2 (A), R4.2
unnamed: J2.A5 (CC1), R2.1
unnamed: J2.B5 (CC2), R3.1
SWCLK: J1.3; also elsewhere on the board
SWDIO: J1.2; also elsewhere on the board
~RESET: J1.4; also elsewhere on the board

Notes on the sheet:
SWD edge connector (unprotected - only for test board)
USB power indicator
ESD protection (place next to USB connector)
USB-C connector

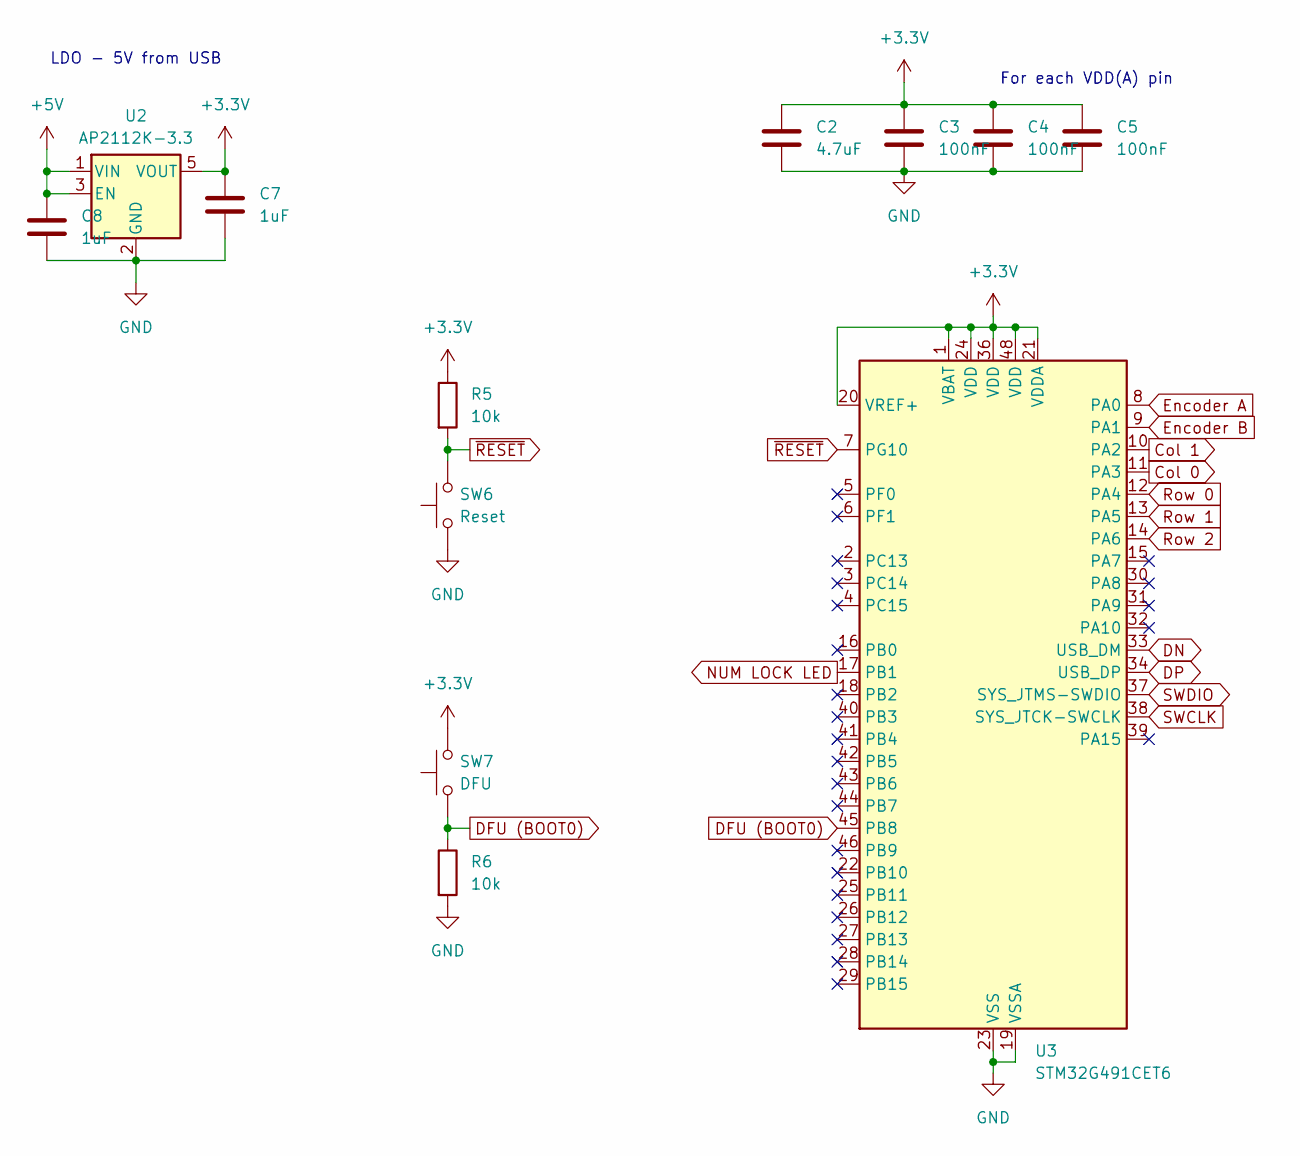
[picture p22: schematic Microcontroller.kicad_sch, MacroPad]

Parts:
C2: 4.7uF; C_0805_2012Metric_Pad1.18x1.45mm_HandSolder; LCSC Part # C1746
C3, C4, C5: 100nF; C_0805_2012Metric_Pad1.18x1.45mm_HandSolder; LCSC Part # C1711
C7, C8: 1uF; C_0805_2012Metric_Pad1.18x1.45mm_HandSolder; LCSC Part # C1712
R5, R6: 10k; R_0805_2012Metric_Pad1.20x1.40mm_HandSolder
SW6: Reset; SW_SPST_PTS645Sx43SMTR92
SW7: DFU; SW_SPST_PTS645Sx43SMTR92
U2: AP2112K-3.3; SOT-23-5_HandSoldering; LCSC Part # C23380830
U3: STM32G491CET6; LQFP-48_7x7mm_P0.5mm; LCSC Part # C3227300

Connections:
+3.3V: C2.1, C3.1, C4.1, C5.1, C7.1, R5.1, SW7.2, U2.5 (VOUT), U3.1 (VBAT), U3.20 (VREF+), U3.21 (VDDA), U3.24 (VDD), U3.36 (VDD), U3.48 (VDD)
+5V: C8.1, U2.1 (VIN), U2.3 (EN); also elsewhere on the board
Col 0: U3.11 (PA3); also elsewhere on the board
Col 1: U3.10 (PA2); also elsewhere on the board
DFU (BOOT0): R6.1, SW7.1, U3.45 (PB8)
DN: U3.33 (USB_DM); also elsewhere on the board
DP: U3.34 (USB_DP); also elsewhere on the board
Encoder A: U3.8 (PA0); also elsewhere on the board
Encoder B: U3.9 (PA1); also elsewhere on the board
GND: C2.2, C3.2, C4.2, C5.2, C7.2, C8.2, R6.2, SW6.1, U2.2 (GND), U3.19 (VSSA), U3.23 (VSS), U3.35 (VSS), U3.47 (VSS); also elsewhere on the board
NUM LOCK LED: U3.17 (PB1); also elsewhere on the board
Row 0: U3.12 (PA4); also elsewhere on the board
Row 1: U3.13 (PA5); also elsewhere on the board
Row 2: U3.14 (PA6); also elsewhere on the board
SWCLK: U3.38 (SYS_JTCK-SWCLK); also elsewhere on the board
SWDIO: U3.37 (SYS_JTMS-SWDIO); also elsewhere on the board
~RESET: R5.2, SW6.2, U3.7 (PG10); also elsewhere on the board

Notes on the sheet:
LDO - 5V from USB
For each VDD(A) pin

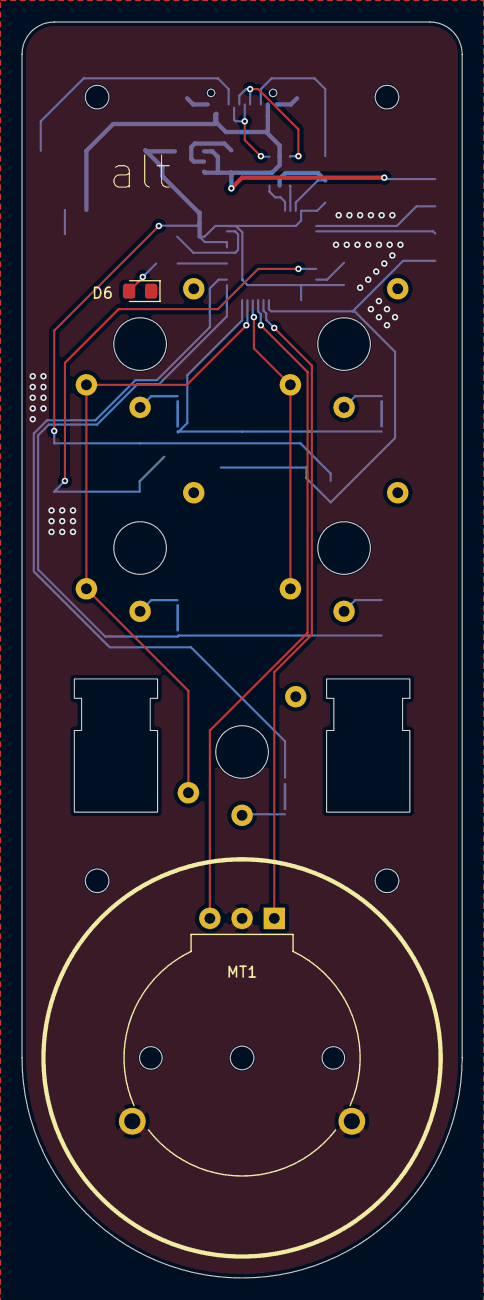
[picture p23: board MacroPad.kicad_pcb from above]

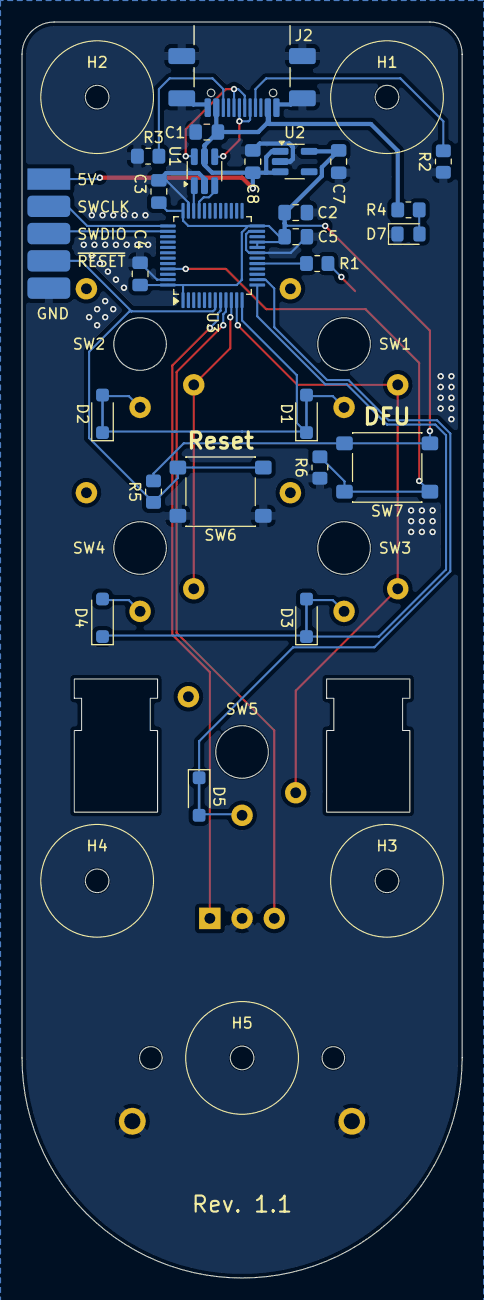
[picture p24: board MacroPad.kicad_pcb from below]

Board: 2 copper layers, 41.0 x 117.0 mm, 38 parts (26 on the bottom side), 28 nets.

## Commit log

2026-08-21 Add BOM
2026-09-14 Add more diodes, adjust num/caps label placement
    Bump board version to 1.1
    Ghosting was a problem with fast typing or button-mashing.
    [DeskFighter.kicad_pcb, DeskFighter.kicad_sch]
